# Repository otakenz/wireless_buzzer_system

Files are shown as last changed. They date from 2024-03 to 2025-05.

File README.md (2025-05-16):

## 🔔 Wireless Buzzer System

A compact and reliable wireless buzzer system built using ESP32-C3, tailored for competitive quiz settings.
Designed for simplicity, affordability, and fast response tracking with up to 5 players,
this system highlights who buzzed in first — all displayed through a GUI.

Created for better accommodating interactive icebreaker sessions and quiz games for missionary trips in
Chiang Rai, Thailand.

Supported by the [**Charis Evangelical Free Church**](https://www.charisefc.org.sg/).

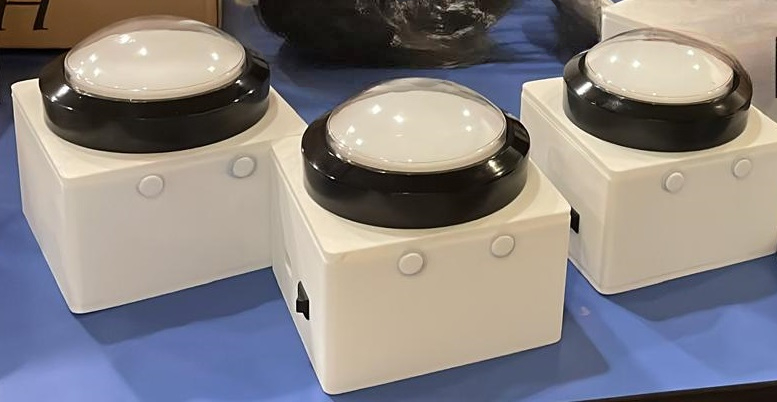
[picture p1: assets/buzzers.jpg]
Buzzers


## ✨ Features

#### 🔧 Custom-built Hardware – Designed using ESP32-C3 with lithium-ion batteries

#### 📶 Wi-Fi Communication – Reliable 1 master ↔ 5 slave setup (20m line of sight)

#### 🧠 Fastest Responder Logic – Master determines the first signal received

#### 💻 Desktop GUI – Shows buzzer order & triggers a win animation

#### 🧩 3D-Printed Cases – Collaborative design finalized across iterations

#### 💸 Low Cost – ~$30 per complete buzzer device

## 🛠️ Tech Stack

| Category | Tools Used |
| --- | --- |
| Hardware | Seeed Studio Xiao Beetle ESP32-C3, 100mm Arcade Buttons, WS2812B 5V LED,<br>Lithium-Ion Battery 3400mAH, 3D Print |
| Firmware | C++ with ESP-NOW |
| Communication | Peer-to-Peer communication through ESP-NOW Wi-Fi stack |
| Diplay App | Simple desktop GUI (e.g. Python + dearpygui + zmq) |
| Tools | PlatformIO, Fusion360 (for CAD) Git |

## 🧪 How It Works

### 📡 System Overview

The system consists of **five wireless buzzers** (based on Seeed Studio Xiao Beetle ESP32-C3)
and **one master controller**, communicating over Wi-Fi. A **desktop GUI** handles visual display
and control through USB serial connection to the master controller.

### 🔄 Application Flow

#### 1. Startup & Registration (SETUP MODE)

- Buttons are turned on manually and wait for acknowledgment (ACK) from the controller.
- Once acknowledged, the buzzer lights up and blinks, and registration is reflected on the GUI.
- PC GUI shows button connection statuses and can trigger the switch to GAME MODE once any
  number of buttons are registered.

#### 2. Gameplay (GAME MODE)

- When ready, the host presses **RESET** on the GUI to prepare for a new round.
- Players press their buzzer as fast as they can.
- The controller determines the first valid press and sends the result to the GUI.
- GUI plays an animation (MP4) corresponding to the winning button.

### 📶 Communication Modes

Option 1 (Current)

- All devices use Wi-Fi STA mode
- Pros: Lower power consumption
- Cons: Button MAC addresses are hardcoded in the controller

Option 2 (Planned/Flexible)

- Buttons act as Wi-Fi AP, controller scans
- Pros: No need to hardcode MACs
- Cons: Slightly higher power usage

### 🔋 Button Device

- Powered by lithium-ion battery
- On boot, attempts connection and waits for ACK
- Upon successful press and ACK:
  - LED blinks to confirm registration
  - Master notifies PC app of readiness
- ESP-NOW handles basic collision handling using a back-off strategy if multiple buttons
  press at the same time

### 🖥️ Controller ↔ PC Interface

- Communicates with the GUI via USB serial (pySerial)
- Responsibilities:
  - Tracks registered buttons during setup
  - Sends winner data during gameplay
  - Receives commands (e.g. RESET, START GAME)

### 🧩 GUI Interface

- Shows each button's status (connected, pressed)
- Displays winner information
- Triggers MP4 animation per button ID from a configurable file path
- Sends RESET commands to controller and updates all button LEDs accordingly

## 🗂️ Project Structure

```bash
wireless_buzzer_system/
├── code/
│ ├── buzzer_button/ # Slave ESP32 firmware (C++ + ESPHome)
│ ├── buzzer_controller/ # Master ESP32 firmware (C++ + ESPHome)
│ ├── buzzer_gui/ # PC GUI display logic
│ └── Instruction.txt # Instructions for how to set up the system
├── pcb/ # Electronic schematic and PCB design files
├── case/ # 3D printable STL files
├── assets/ # Images
└── README.md
```

## 📝 Development Notes

- Built in ~1 month as a two-person team:
  - Hardware + firmware: primary focus (me)
  - Enclosure design + assembly: partner
- Fairness tuning not implemented due to time constraint (players are within similar distances)
- System tuned for simplicity and practical use over perfection

## 📘 References

- [ESPNOW](https://docs.espressif.com/projects/esp-idf/en/stable/esp32/api-reference/network/esp_now.html)
- [Example of using espnow with buttons](https://github.com/makermoekoe/Picoclick-C3/tree/main/code/Picoclick_C3)
- [How to Create A Sports Button](https://www.youtube.com/watch?v=HAt3EoVqO7I)
- [Seeed Xiao ESP32-C3 Schematic](https://wiki.seeedstudio.com/XIAO_ESP32C3_Getting_Started/)

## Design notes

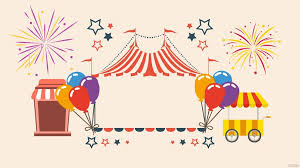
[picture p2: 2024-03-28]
code/buzzer_gui/assets/design/carnival4.jpeg

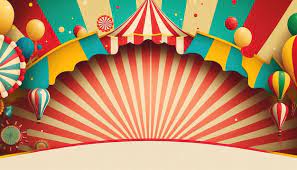
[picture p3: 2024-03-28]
code/buzzer_gui/assets/design/carnival1.jpeg

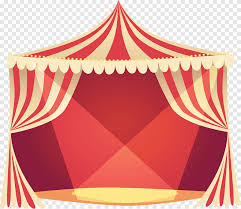
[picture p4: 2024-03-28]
code/buzzer_gui/assets/design/carnival2.jpeg

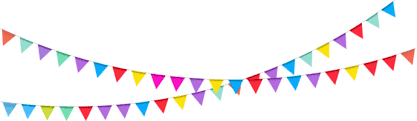
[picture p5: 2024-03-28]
code/buzzer_gui/assets/design/carnival3.png

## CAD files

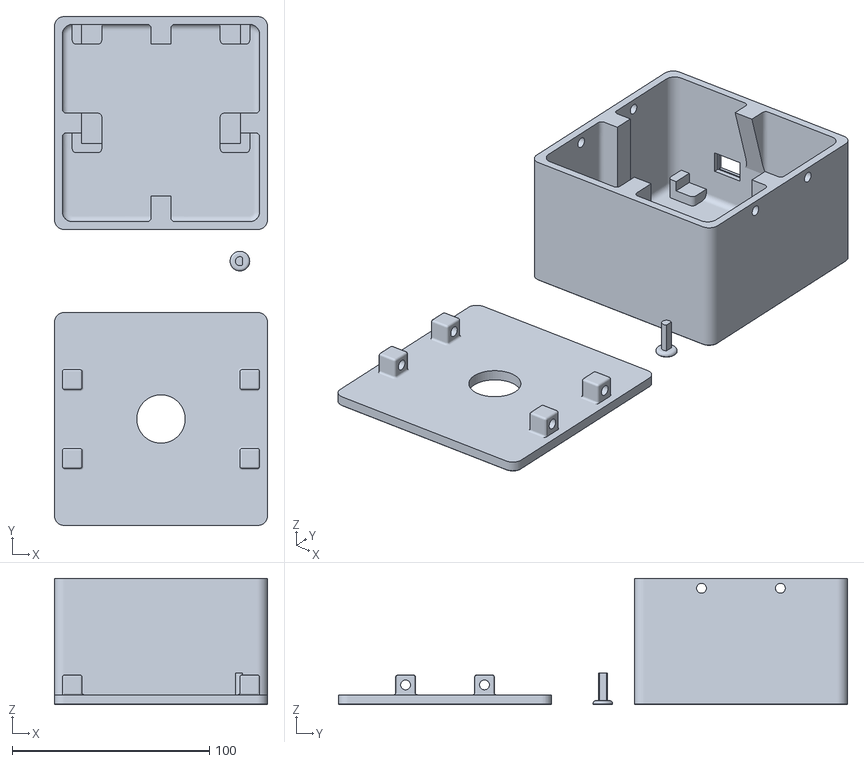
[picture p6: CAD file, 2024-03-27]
case/MT24_ButtonCase_v2 v13.stl
108.0 x 258.0 x 64.0

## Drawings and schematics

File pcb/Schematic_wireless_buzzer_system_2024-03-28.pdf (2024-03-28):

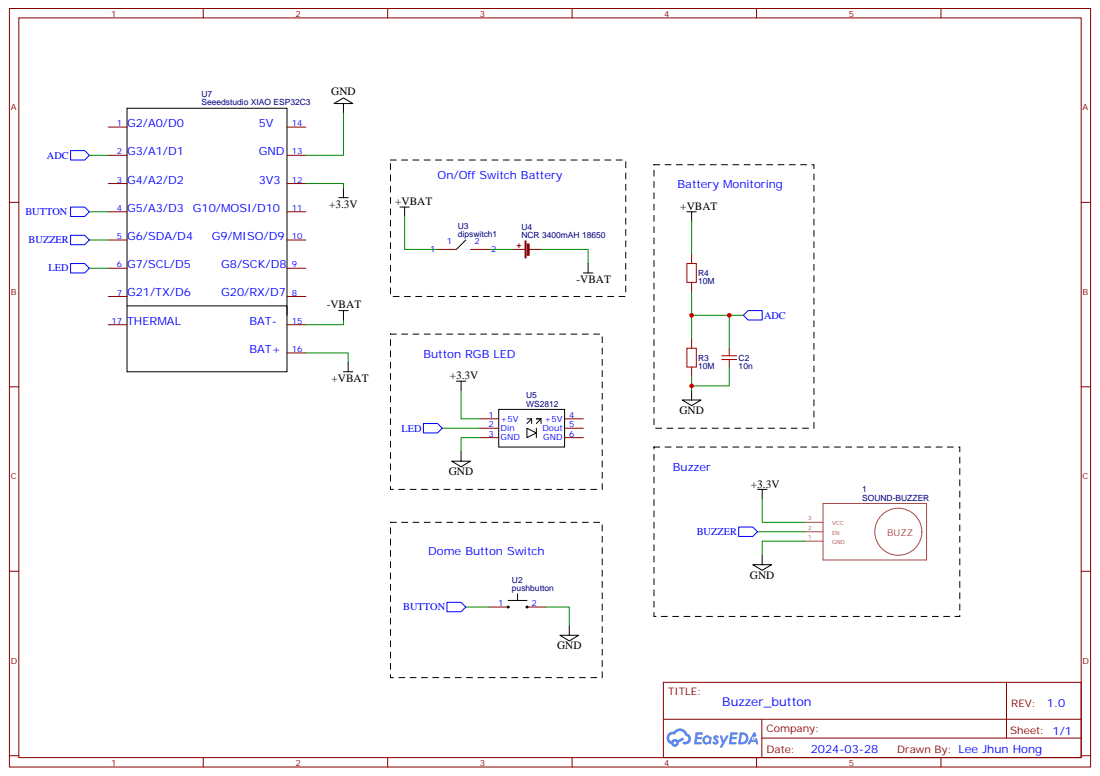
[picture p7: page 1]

On/Off Switch Battery

Drawn By: Lee Jhun Hong

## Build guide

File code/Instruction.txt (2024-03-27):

Prerequisite of your IDE: PlatformIO extension, libraries (cv2,zmq,dearpygui)

buzzer_mp4_config.json: To update the MP4 files, reposition and resize the MP4 video GUI
buzzer_score_config.json: To update the starting score of the 5 teams, reposition and resize the scoreboard GUI

Here are the instructions on how you should run the program:

Initial setup before the start of the game, even before the players are on stage ...
1. Run the following three python scripts in a separate terminal (they are located under /wireless_buzzer_system/code/buzzer_gui/)
    a. buzzer_gui.py (Main GUI for us to check status, control button behaviour or debug)
    b. buzzer_mp4.py (GUI to display the media for the fastest button)
    c. buzzer_score.py (GUI to display the scoreboard of the current game)
2. Connecting the buttons
    a. Plug in the main controller to your PC via USB-C. Click the dropdown in the COM window, and choose your port. Then click 'Select' on your right.
    b. Switch on the buttons, then click 'SCAN'.
        i. You should see the number of buttons that was switched on should match the number of buttons online from your GUI. If it matches, jump to step 3, else readon.
        ii. In case they are not tallied (ie: buttons switched on but not detected by your GUI), click the Button box from your GUI to ping each button (pinged button will flash).
        iii. By pinging it one by one, you can identify which button is having issue and not lighted up.
        iv. Switch off the problematic button and repeat Step 2b.
3. Now you should have all the buttons on and detected by your GUI, arrange them accordingly on stage for the 5 players.
    a. Make sure they are in order by pinging it again (click the Button box from your GUI).
    NOTE: Do not press 'SCAN' more than one time or it will mess up the button sequence and you will need to rearrange the button.

Now you should be ready to start the game ...
4. Locking Mechanism
    a. By default, the GUI should show 'Locked' at the Locking Mechanism Window on your right. This is to lock the button and block all the inputs and outputs from our system before players are allowed to push the button and answer.
    b. Click on the 'Locked' button once a question is ready to be answer and players are ready to press the button, so that the button will be unlocked for answering.
    c. To make sure, you should see the Locked button is now showing Unlocked.
5. Scoring
    a. Once there is a winner for the fastest button pressed, the MP4 GUI pop up indicating which team is the fastest to press the button.
    b. Input how many points to award or deduct for this team in the Score Input window, depending if they answer the question correctly or not.
    c. Press '+' or '-' based on the situation whether they are getting points or deducting points.
    d. Scores updated in the scoreboard GUI.
6. Resetting the game
    a. Press 'RESET' from your GUI after one round is over, to reset the game and prepare for the next round.
    b. When you reset the game, the button will automatically be Locked and now repeat from Step 4b.
    NOTE: If the number of points to be added/subtracted is the same throughout the entire round you can skip Step 5b.

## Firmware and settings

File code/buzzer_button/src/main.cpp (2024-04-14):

#include "custom_print.h"
#include "esp32-hal-adc.h"
#include "esp32-hal-gpio.h"
#include "esp32-hal-timer.h"
#include "esp_mac.h"
#include <Adafruit_NeoPixel.h>
#include <WiFi.h>
#include <cstdint>
#include <cstdlib>
#include <esp_now.h>
#include <esp_wifi.h> // only for esp_wifi_set_channel()
#include <sys/types.h>

#define CHANNEL 11

// xiao setting
#define LED_PIN 7
#define BUZZER_PIN 6
#define BUTTON_PIN 5
#define ADC_PIN 3
#define LED_COUNT 1

// battery
#define NUM_READINGS 16          // Number of readings for moving average
uint32_t readings[NUM_READINGS]; // Array to store voltage readings
uint8_t i = 0;    // i to track the current position in the readings array
uint32_t sum = 0; // Sum of voltage readings

Adafruit_NeoPixel RGB_LED =
    Adafruit_NeoPixel(LED_COUNT, LED_PIN, NEO_GRB + NEO_KHZ800);

constexpr uint8_t controller[] = {0x54, 0x32, 0x04, 0x89, 0x15, 0x50};
constexpr uint8_t broadcast_mac[] = {0xFF, 0xFF, 0xFF, 0xFF, 0xFF, 0xFF};

typedef struct struct_message_button {
  uint8_t local_mac[6];
  uint8_t battery_level;
} struct_message_button;

typedef struct struct_message_controller {
  bool pressed;
  bool lock;
  bool ping;
  uint8_t winner_mac[6];
} struct_message_controller;

struct_message_button buttonData;
struct_message_controller controllerData;
esp_now_peer_info_t controllerInfo;
esp_now_peer_info_t broadcastInfo;

void check_esp_err(esp_err_t result) {
  print("Send Status: ");
  switch (result) {
  case ESP_OK:
    println("Pair success");
    break;
  case ESP_ERR_ESPNOW_FULL:
    println("Peer list full");
    break;
  case ESP_ERR_ESPNOW_EXIST:
    println("Peer Exists");
    break;
  case ESP_ERR_ESPNOW_NOT_INIT:
    println("ESPNOW not Init.");
    break;
  case ESP_ERR_ESPNOW_ARG:
    println("Invalid Argument");
    break;
  case ESP_ERR_ESPNOW_INTERNAL:
    println("Internal Error");
    break;
  case ESP_ERR_ESPNOW_NO_MEM:
    println("ESP_ERR_ESPNOW_NO_MEM");
    break;
  case ESP_ERR_ESPNOW_NOT_FOUND:
    println("Peer not found.");
    break;
  case ESP_ERR_ESPNOW_IF:
    println("Interface error.");
    break;
  default:
    println("Not sure what happened");
    break;
  }
}

// Init ESP Now with fallback
void InitESPNow() {
  WiFi.disconnect();
  if (esp_now_init() == ESP_OK) {
    println("ESPNow Init Success");
  } else {
    println("ESPNow Init Failed");
    // Retry InitESPNow, add a counte and then restart?
    // InitESPNow();
    // or Simply Restart
    ESP.restart();
  }
}

// Fill the dots with one color
void colorWipe(uint32_t c) {
  for (uint16_t i = 0; i < RGB_LED.numPixels(); i++) {
    RGB_LED.setPixelColor(i, c);
    RGB_LED.show();
  }
}

void sendButtonData() {
  if (controllerData.pressed) {
    return;
  }
  if (controllerData.lock) {
    return;
  }
  esp_read_mac(buttonData.local_mac, ESP_MAC_WIFI_STA);
  /* buttonData.battery_level = static_cast<uint8_t>(get_battery_percentage());
   */
  /* Serial.println("Battery level: " + String(buttonData.battery_level)); */
  /* buttonData.battery_level = random(0, 100); */
  // Send message via ESP-NOW
  println("Sending battery level: " + String(buttonData.battery_level));

  esp_err_t result =
      esp_now_send(controller, (uint8_t *)&buttonData, sizeof(buttonData));
  check_esp_err(result);
}

// config AP SSID
void configDeviceAP() {
  String Prefix = "Slave:";
  String Mac = WiFi.macAddress();
  String SSID = Prefix + Mac;
  String Password = "t=_Z}ex4v+W'TI1ZnE$'";
  bool result = WiFi.softAP(SSID.c_str(), Password.c_str(), CHANNEL, 0);
  if (!result) {
    println("AP Config failed.");
  } else {
    println("AP Config Success. Broadcasting with AP: " + String(SSID));
  }
}

bool compareMacAddress(const uint8_t *mac1, const uint8_t *mac2) {
  for (int i = 0; i < 6; ++i) {
    if (mac1[i] != mac2[i]) {
      return false;
    }
  }
  return true;
}

// Callback when data is sent
void OnDataSent(const uint8_t *mac_addr, esp_now_send_status_t status) {
  print("\r\nLast Packet Send Status:\t");
  println(status == ESP_NOW_SEND_SUCCESS ? "Delivery Success"
                                         : "Delivery Fail");
}

// callback when data is recv from Master
void OnDataRecv(const uint8_t *mac_addr, const uint8_t *data, int data_len) {

  memcpy(&controllerData, data, sizeof(controllerData));

  if (controllerData.lock) {
    return;
  }

  if (controllerData.pressed) {
    if (compareMacAddress(controllerData.winner_mac, buttonData.local_mac)) {
      println("Controller: You won!");
      colorWipe(RGB_LED.Color(255, 0, 0));
    } else {
      println("Controller: Someone pressed the button first!");
    }
  } else {
    println("Controller: reset LED!");
    colorWipe(RGB_LED.Color(0, 0, 0));
  }

  if (controllerData.ping) {
    println("Ping from controller received!");
    controllerData.ping = false;
    for (uint8_t i = 0; i < 3; i++) {
      colorWipe(RGB_LED.Color(0, 255, 0));
      delay(500);
      colorWipe(RGB_LED.Color(0, 0, 255));
      delay(500);
    }
    colorWipe(RGB_LED.Color(0, 0, 0));
    // TODO: flicker LED in blue for a short time
  }

  print("Bytes received: ");
  println(data_len);
}

void IRAM_ATTR onButtonTimer() {
  if (digitalRead(BUTTON_PIN) == LOW) {
    sendButtonData();
  }
}

hw_timer_t *read_button_timer = NULL;

void setup() {
  Serial.begin(115200);

  pinMode(BUTTON_PIN, INPUT_PULLUP);
  pinMode(ADC_PIN, INPUT);
  pinMode(LED_PIN, OUTPUT);
  pinMode(BUZZER_PIN, OUTPUT);
  analogReadResolution(12);
  /* analogSetAttenuation(ADC_ATTENDB_MAX); // Set attenuation to 11 dB */

  // Initialize readings array to 0
  memset(readings, 0, sizeof(uint32_t) * NUM_READINGS);

  btStop();

  // Set device in AP mode to begin with
  WiFi.mode(WIFI_MODE_APSTA);
  // configure device AP mode
  configDeviceAP();
  /* esp_wifi_set_channel(CHANNEL, WIFI_SECOND_CHAN_NONE); */

  // This is the mac address of the Slave in AP Mode
  print("AP MAC: ");
  println(WiFi.softAPmacAddress());

  // Init ESP-NOW
  InitESPNow();

  RGB_LED.begin();
  RGB_LED.show(); // Disable all the pixel by default when initialized
  RGB_LED.setBrightness(255); // Set brightness

  // Once ESPNow is successfully Init, we will register for Send CB to
  // get the status of Trasnmitted packet
  esp_now_register_send_cb(OnDataSent);

  // Register peer
  memcpy(controllerInfo.peer_addr, controller, 6);
  controllerInfo.channel = CHANNEL;
  controllerInfo.encrypt = false;

  // Add peer
  if (esp_now_add_peer(&controllerInfo) != ESP_OK) {
    println("Failed to add peer");
    return;
  }

  memcpy(broadcastInfo.peer_addr, broadcast_mac, 6);
  broadcastInfo.channel = CHANNEL;
  broadcastInfo.encrypt = false;

  // Add peer
  if (esp_now_add_peer(&broadcastInfo) != ESP_OK) {
    println("Failed to add peer");
    return;
  }

  // Register for a callback function that will be called when data is received
  esp_now_register_recv_cb(OnDataRecv);

  /* attachInterrupt(digitalPinToInterrupt(BUTTON_PIN), sendButtonData,
   * FALLING); */
  read_button_timer = timerBegin(0, 80, true);
  timerAttachInterrupt(read_button_timer, &onButtonTimer, true);
  timerAlarmWrite(read_button_timer, 20000, true);
  timerAlarmEnable(read_button_timer);

  controllerData.lock = true;
}

uint8_t count = 0;

uint8_t get_battery_level() {
  // Read voltage and update rolling
  uint32_t voltage = analogReadMilliVolts(ADC_PIN); // Read battery voltage
  sum = sum - readings[i] + voltage;                // Update rolling sum
  readings[i] = voltage;      // Store current voltage reading in array
  i = (i + 1) % NUM_READINGS; // Increment i and wrap around if needed

  // Calculate moving average
  float Vbattf =
      2 * sum /
      (NUM_READINGS * 1000.0); // Calculate average voltage in volts (V)

  // Calculate voltage percentage
  float voltagePercentage;
  if (Vbattf >= 4.2) {
    voltagePercentage = 100;
  } else if (Vbattf <= 3) {
    voltagePercentage = 0;
  } else {
    voltagePercentage = (Vbattf - 3) / (4.2 - 3) * 100;
  }

  Serial.println("Battery voltage: " + String(Vbattf, 3) + " V");
  Serial.println(voltagePercentage, 1);

  if (count < 20) {
    delay(1000);
    count++;
  } else {
    delay(1000);
    /* delay(5000); */
  }

  return static_cast<uint8_t>(voltagePercentage);
}

// Main loop
void loop() { buttonData.battery_level = get_battery_level(); }

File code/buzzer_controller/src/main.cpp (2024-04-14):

#include "HWCDC.h"
#include "custom_print.h"
#include <WiFi.h>
#include <cstdint>
#include <esp_now.h>

// Global copy of slave
#define NUMSLAVES 5
#define CHANNEL 11

bool someone_has_pressed = false;

typedef struct struct_message_button {
  uint8_t local_mac[6];
  uint8_t battery_level;
} struct_message_button;

typedef struct struct_message_controller {
  bool pressed;
  bool lock;
  bool ping;
  uint8_t winner_mac[6];
} struct_message_controller;

typedef struct struct_message_pc {
  uint8_t buttons_mac[NUMSLAVES][6];
  uint8_t battery_level[NUMSLAVES];
  int32_t RSSI[NUMSLAVES];
  uint8_t status[NUMSLAVES];
} struct_message_pc;

struct_message_button buttonData;
struct_message_controller controllerData;
struct_message_pc pcData;
esp_now_peer_info_t broadcastInfo;

esp_now_peer_info_t slaves[NUMSLAVES] = {};

int regSlavesCnt = 0;
String SSID = "";
int32_t RSSI = 0;
String BSSIDstr = "";
bool scanList[NUMSLAVES] = {false, false, false, false, false};

const String buttons_ssid[] = {"54:32:04:87:B5:A4", "54:32:04:87:B2:B0",
                               "54:32:04:89:06:8C", "54:32:04:87:4C:EC",
                               "64:E8:33:80:BE:FC"};
/* const String buttons_ssid[] = {"54:32:04:89:27:E4", "54:32:04:87:27:C4", */
/*                                "54:32:04:87:27:CC", "54:32:04:87:27:DC", */
/*                                "54:32:04:87:27:EC"}; */

constexpr uint8_t broadcast_mac[] = {0xFF, 0xFF, 0xFF, 0xFF, 0xFF, 0xFF};

void check_esp_err(esp_err_t result) {
  print("Send Status: ");
  switch (result) {
  case ESP_OK:
    println("Pair success");
    break;
  case ESP_ERR_ESPNOW_FULL:
    println("Peer list full");
    break;
  case ESP_ERR_ESPNOW_EXIST:
    println("Peer Exists");
    break;
  case ESP_ERR_ESPNOW_NOT_INIT:
    println("ESPNOW not Init.");
    break;
  case ESP_ERR_ESPNOW_ARG:
    println("Invalid Argument");
    break;
  case ESP_ERR_ESPNOW_INTERNAL:
    println("Internal Error");
    break;
  case ESP_ERR_ESPNOW_NO_MEM:
    println("ESP_ERR_ESPNOW_NO_MEM");
    break;
  case ESP_ERR_ESPNOW_NOT_FOUND:
    println("Peer not found.");
    break;
  case ESP_ERR_ESPNOW_IF:
    println("Interface error.");
    break;
  default:
    println("Not sure what happened");
    break;
  }
}

// Init ESP Now with fallback
void InitESPNow() {
  WiFi.disconnect();
  if (esp_now_init() == ESP_OK) {
    println("ESPNow Init Success");
  } else {
    println("ESPNow Init Failed");
    // Retry InitESPNow, add a counte and then restart?
    // InitESPNow();
    // or Simply Restart
    ESP.restart();
  }
}

// config AP SSID
void configDeviceAP() {
  String Prefix = "Master:";
  String Mac = WiFi.macAddress();
  String SSID = Prefix + Mac;
  String Password = "t=_Z'TI1ZnE$'}ex4v+W";
  bool result = WiFi.softAP(SSID.c_str(), Password.c_str(), CHANNEL, 1);
  if (!result) {
    Serial.println("AP Config failed.");
  } else {
    Serial.println("AP Config Success. Broadcasting with AP: " + String(SSID));
  }
}

bool compareMacAddress(const uint8_t *mac1, const uint8_t *mac2) {
  for (int i = 0; i < 6; ++i) {
    if (mac1[i] != mac2[i]) {
      return false;
    }
  }
  return true;
}

String macToString(const uint8_t *mac) {
  char macStr[18]; // Buffer to hold the string representation of the MAC

  // Format the MAC address into the buffer
  snprintf(macStr, sizeof(macStr), "%02X:%02X:%02X:%02X:%02X:%02X", mac[0],
           mac[1], mac[2], mac[3], mac[4], mac[5]);

  // Return the formatted MAC address as a String
  return String(macStr);
}

void slavesSetUp() {
  for (int i = 0; i < NUMSLAVES; i++) {
    uint8_t temp_address[6];

    sscanf(buttons_ssid[i].c_str(), "%x:%x:%x:%x:%x:%x", &temp_address[0],
           &temp_address[1], &temp_address[2], &temp_address[3],
           &temp_address[4], &temp_address[5]);

    memcpy(slaves[i].peer_addr, temp_address, 6);

    slaves[i].channel = CHANNEL; // pick a channel
    slaves[i].encrypt = 0;       // no encryption
  }
}

// Check if the slave is already paired with the master.
// If not, pair the slave with master
void manageSlave() {
  for (int i = 0; i < NUMSLAVES; i++) {
    print("Attempt to pair with Slave: ");

    println(macToString(slaves[i].peer_addr));

    // check if the peer exists
    bool exists = esp_now_is_peer_exist(slaves[i].peer_addr);

    if (!exists && regSlavesCnt < NUMSLAVES) {
      // Slave not paired, attempt pair
      esp_err_t addStatus = esp_now_add_peer(&slaves[i]);
      check_esp_err(addStatus);
      if (addStatus == ESP_OK) {
        memcpy(&pcData.buttons_mac[i], slaves[i].peer_addr, 6);
        regSlavesCnt++;
      }
      delay(100);

    } else {
      // Slave already paired.
      println("Already Paired");
    }
  }
}

// Scan for slaves in AP mode
void ScanForSlave() {
  int8_t scanResults =
      /* WiFi.scanNetworks(false, false, false, 300, CHANNEL, buttons_ssid); */
      WiFi.scanNetworks(false, false, false, 300, CHANNEL);

  // reset slaves
  /* memset(slaves, 0, sizeof(slaves)); */
  /* println(""); */

  if (scanResults == 0) {
    println("No WiFi devices in AP Mode found");
    return;
  }

  print("Found ");
  print(scanResults);
  println(" devices ");

  uint8_t count = 0;

  // processing this current scan results
  for (int i = 0; i < scanResults; ++i) {
    // Print SSID and RSSI for each device found
    SSID = WiFi.SSID(i);
    RSSI = WiFi.RSSI(i);
    BSSIDstr = WiFi.BSSIDstr(i);

    delay(10);

    // Check if the current device starts with `Slave`
    if (SSID.indexOf("Slave") != 0)
      continue;

    count++;

    // SSID of interest
    print(i + 1);
    print(": ");
    print(SSID);
    print(" [");
    print(BSSIDstr);
    print("]");
    print(" (");
    print(RSSI);
    print(")");
    println("");
    // Get BSSID => Mac Address of the Slave
    uint8_t mac[6];

    if (6 != sscanf(SSID.c_str(), "Slave:%x:%x:%x:%x:%x:%x", &mac[0], &mac[1],
                    &mac[2], &mac[3], &mac[4], &mac[5])) {
      println("Failed to parse SSID");
      continue;
    }

    // Check if the current device is already paired with the master.
    for (uint8_t i = 0; i < NUMSLAVES; i++) {
      auto slaveFound = compareMacAddress(mac, pcData.buttons_mac[i]);
      if (slaveFound) {
        println("Slave no " + String(i) + " found");
        pcData.RSSI[i] = RSSI;
        pcData.status[i] = 1;
        scanList[i] = true;
        break;
      }
    }
  }

  for (uint8_t i = 0; i < NUMSLAVES; i++) {
    if (!scanList[i]) {
      println("Slave no " + String(i) + " not found");
      pcData.RSSI[i] = 0;
      pcData.status[i] = 0;
    }
    scanList[i] = false;
  }

  if (count == 0) {
    // If none of slaves found, reset the RSSI and status
    for (uint8_t i = 0; i < NUMSLAVES; i++) {
      pcData.RSSI[i] = 0;
      pcData.status[i] = 0;
    }
  }
  /* manageSlave(); */

  // clean up ram
  WiFi.scanDelete();
}
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

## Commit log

2024-03-01 Initial working button / controller
2024-03-06 GUI buttons addition
2024-03-09 Initial kinda working demo for features: 1, scan for buttons, 2, ping button with onboard led, 3, winner on gui, 4, reset buttons and gui
2024-03-09 Battery data
2024-03-16 update new buttons
2024-03-16 some fix on gui
    [buzzer_gui.py]
2024-03-16 why ffpyplayer and opencv has some issue together, cannot see the image more than 1 time if use threading.. many bugs demo
    [buzzer_gui.py]
2024-03-19 Fixed video player threading issue with zmq
    [buzzer_gui.py, buzzer_mp4.py]
2024-03-25 add locking to controller and button
2024-03-25 Reset will lock the button
    [buzzer_gui.py]
2024-03-27 Add files via upload
    Button casing to store the circuitry of the button
    [MT24_ButtonCase_v2 v13.stl]
2024-03-27 Implemented hardcoded way of identifying buttons, changes on controller and gui
2024-03-28 use real button ssid
2024-03-28 Add schematic design pdf
2024-04-04 fix bug, unable to determine if button is offline
    [main.cpp]
